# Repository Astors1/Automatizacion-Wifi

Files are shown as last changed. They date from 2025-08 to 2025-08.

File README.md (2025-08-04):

# Automatizacion wifi
Proyecto: Automatizaación WIFI Y infrarrojo. Alumnos: Alliana Facundo y Agustin Astorga ,con colaboracion de Alejo Guerra. Profesor: Martin Leguizamon. *Descripción del proyecto: Este dispositivo actúa como un control de tomacorrientes, donde se pueden agregar diferentes dispositivos, y permite apagarlos o prenderlos mediante una página web con interruptores. Además, cuenta con un sistema de control de seguridad (solo se puede activar manualmente)por infrarrojo, en caso de que no sea posible conectarse por WiFi. Objetivo: El objetivo principal es mejorar el control de dispositivos (luces, herramientas, etc.) de manera más práctica y permitir su manejo a distancia. En versiones anteriores, este dispositivo funcionaba mediante Bluetooth, lo que presentaba varias limitaciones: un alcance de solo 1 metro y la necesidad de instalar una aplicación en el teléfono móvil para su uso. En esta nueva versión, se mejorará la conexión a través de WiFi, lo que permitirá un mayor alcance y eliminará la necesidad de instalar aplicaciones adicionales, ya que funcionará mediante una dirección IP. Sin embargo, para situaciones en las que no se disponga de WiFi, el dispositivo contará con una opción de control por infrarrojos, que se podrá activar manualmente. Esta opción tendrá un alcance más limitado, pero ofrecerá una solución práctica y segura para su control. Listado de materiales/fuentes: • Microcontrolador ESP32/ (embebido reciclado) • Resistencias/optocopladores /transistores/pulsadores/rectificadores, etc (reciclados) • Relays x4 (reciclados) • Módulo infrarrojo (emisor/transmisor) ($8.000) • placa cobre doble faz (ya comprada) • Estaño, conectores, cables, etc ($10.000) Costo aproximado: $20.000.

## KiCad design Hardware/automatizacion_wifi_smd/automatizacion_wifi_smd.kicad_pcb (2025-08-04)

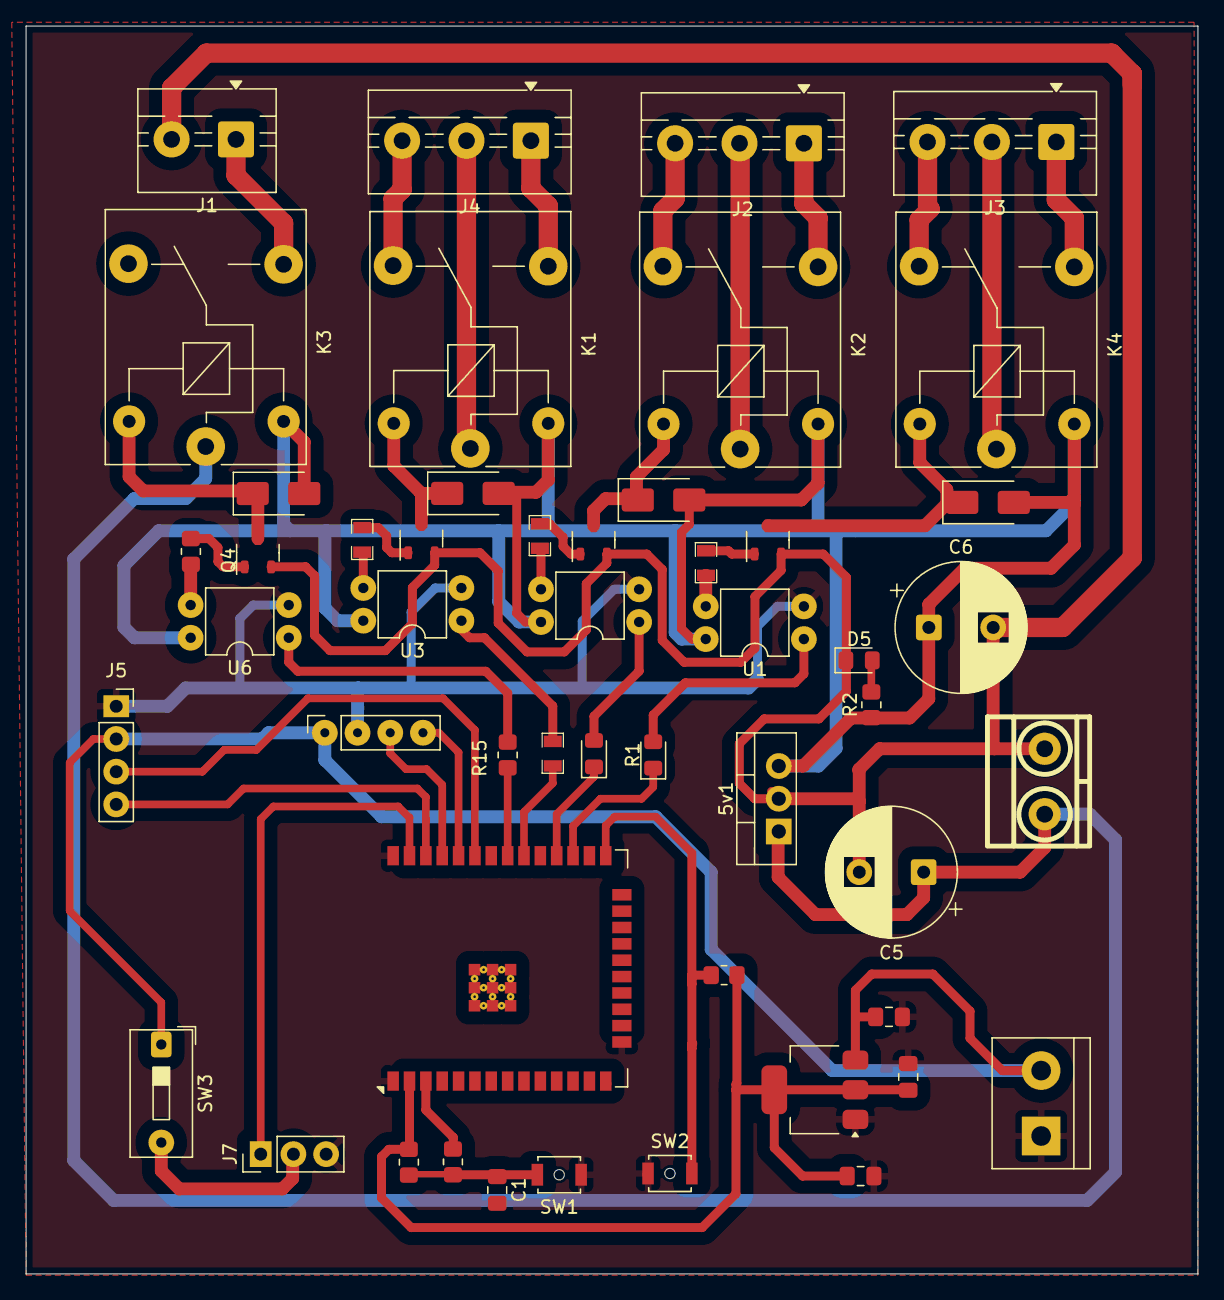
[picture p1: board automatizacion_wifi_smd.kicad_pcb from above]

Board: 2 copper layers, 91.0 x 96.9 mm, 50 parts (0 on the bottom side), 46 nets.

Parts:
5v1: LM7805_TO220; TO-220-3_Vertical
C1: 100nF; C_0805_2012Metric_Pad1.18x1.45mm_HandSolder
C2, C4: 10 uF; C_0805_2012Metric_Pad1.18x1.45mm_HandSolder
C3: 100 nF; C_0805_2012Metric_Pad1.18x1.45mm_HandSolder
C5, C6: 100uf; CP_Radial_D10.0mm_P5.00mm
D1, D2, D3, D4: DIODE; D_SMA
D5: LED; LED_0805_2012Metric_Pad1.15x1.40mm_HandSolder
J1: Screw_Terminal_01x02; TerminalBlock_MaiXu_MX126-5.0-02P_1x02_P5.00mm
J2, J3, J4: Screw_Terminal_01x03; TerminalBlock_MaiXu_MX126-5.0-03P_1x03_P5.00mm
J5, J6: Conn_01x04_Pin; PinSocket_1x04_P2.54mm_Vertical
J7: Conn_01x03_Pin; PinHeader_1x03_P2.54mm_Vertical
K1, K2, K3, K4: RELAY_C; Relay_SPDT_SANYOU_SRD_Series_Form_C
Q1, Q2, Q3, Q4: 2N3904; P200_SOT-23
R1, R4: R; LED_0805_2012Metric_Pad1.15x1.40mm_HandSolder
R2: 2.2k; R_0805_2012Metric_Pad1.20x1.40mm_HandSolder
R3, R6, R9: R; R_0805
R7: 1k; R_0805
R10, R11, R12: 10K; R_0805_2012Metric_Pad1.20x1.40mm_HandSolder
R15, R17: R; R_0805_2012Metric_Pad1.20x1.40mm_HandSolder
SW1, SW2: SW_Push; SW_SPST_B3U-1000P-B
SW3: SW_SPST; SW_DIP_SPSTx01_Slide_9.78x4.72mm_W7.62mm_P2.54mm
U1, U2, U3, U6: PC817; DIP-4_W7.62mm
U4: ESP32-WROOM-32E__4MB_; ESP32-WROOM-32E
U5: NCP1117-1.5_SOT223; SOT-223-3_TabPin2
bornera1: bornera; BORNERA2_AZUL
bornera2: bornera; TerminalBlock_bornier-2_P5.08mm

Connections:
/3.3V: C3.2, C4.1, R10.1, R11.1, U4.2 (3V3), U5.2 (VO)
/5V: 5v1.3 (VO), C6.1, D1.2 (K), D2.2 (K), D3.2 (K), D4.2 (K), K1.2, K2.2, K3.2, K4.2, R2.1, U1.4, U2.4, U3.4, U6.4
/5VES: C2.1, J5.2, J6.1, SW3.1 (A), U5.3 (VI), bornera2.2
/C1: J4.2, K1.1
/C2: J3.2, K4.1
/C3: J2.2, K2.1
/EN: R12.2, U4.3 (EN)
/FLASH: R11.2, SW2.2, U4.25 (IO0)
/GNDE: C1.2, C2.2, C3.1, C4.2, J5.1, J6.2, J7.3, SW1.1, SW2.1, U1.2, U2.2, U3.2, U4.1 (GND), U4.15 (GND), U4.38 (GND), U5.1 (GND), U6.2, bornera2.1
/NC1: J4.3, K1.4
/NC2: J3.3, K4.4
/NC3: J2.3, K2.4
/NO1: J4.1, K1.3
/NO2: J3.1, K4.3
/NO3: J2.1, K2.3
/NO4: J1.1, K3.3
/R1: R7.1, U4.30 (IO18)
/R2: R1.1, U4.27 (IO16)
/R3: R4.1, U4.28 (IO17)
/R4: R15.1, U4.31 (IO19)
/RX: J6.4, U4.34 (RXD0)
/S: J7.1, U4.37 (IO23)
/SCL: J5.4, U4.36 (IO22)
/SDA: J5.3, U4.33 (IO21)
/SWITCH: C1.1, R10.2, R12.1, SW1.2
/TX: J6.3, U4.35 (TXD0)
/VIN: C5.1, K3.1, bornera1.1
GND: 5v1.2 (GND), C5.2, C6.2, D5.1 (K), J1.2, Q1.2 (E), Q2.2 (E), Q3.2 (E), Q4.2 (E), bornera1.2
unnamed: D1.1 (A), K4.5, Q3.3 (C)
unnamed: D2.1 (A), K2.5, Q2.3 (C)
unnamed: D3.1 (A), K1.5, Q1.3 (C)
unnamed: D4.1 (A), K3.5, Q4.3 (C)
unnamed: D5.2 (A), R2.2
unnamed: J7.2, SW3.2 (B)
unnamed: Q1.1 (B), R9.2
unnamed: Q2.1 (B), R6.2
unnamed: Q3.1 (B), R3.2
unnamed: Q4.1 (B), R17.2
unnamed: R1.2, U1.1
unnamed: R3.1, U1.3
unnamed: R4.2, U2.1
unnamed: R6.1, U2.3
unnamed: R7.2, U3.1
unnamed: R9.1, U3.3
unnamed: R15.2, U6.1
unnamed: R17.1, U6.3

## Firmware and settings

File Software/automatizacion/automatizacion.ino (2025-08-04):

#include <WiFi.h>

const char* ssid = "ZTE";
const char* password = "mesi1234";

WiFiServer server(80);
String header;

// Estados de los pines
String output16State = "off";
String output17State = "off";
String output18State = "off";
String output19State = "off";

// Pines utilizados
const int output16 = 16;
const int output17 = 17;
const int output18 = 18;
const int output19 = 19;

unsigned long currentTime = millis();
unsigned long previousTime = 0; 
const long timeoutTime = 2000;

void setup() {
  Serial.begin(115200);
  pinMode(output16, OUTPUT);
  pinMode(output17, OUTPUT);
  pinMode(output18, OUTPUT);
  pinMode(output19, OUTPUT);

  digitalWrite(output16, LOW);
  digitalWrite(output17, LOW);
  digitalWrite(output18, LOW);
  digitalWrite(output19, LOW);

  Serial.print("Connecting to ");
  Serial.println(ssid);
  WiFi.begin(ssid, password);
  while (WiFi.status() != WL_CONNECTED) {
    delay(500);
    Serial.print(".");
  }
  Serial.println("");
  Serial.println("WiFi connected.");
  Serial.println("IP address: ");
  Serial.println(WiFi.localIP());
  server.begin();
}

void loop() {
  WiFiClient client = server.available();

  if (client) {
    currentTime = millis();
    previousTime = currentTime;
    Serial.println("New Client.");
    String currentLine = "";

    while (client.connected() && currentTime - previousTime <= timeoutTime) {
      currentTime = millis();
      if (client.available()) {
        char c = client.read();
        Serial.write(c);
        header += c;
        if (c == '\n') {
          if (currentLine.length() == 0) {
            client.println("HTTP/1.1 200 OK");
            client.println("Content-type:text/html");
            client.println("Connection: close");
            client.println();

            // Control de pines
            if (header.indexOf("GET /16/on") >= 0) {
              Serial.println("GPIO 16 on");
              output16State = "on";
              digitalWrite(output16, HIGH);
            } else if (header.indexOf("GET /16/off") >= 0) {
              Serial.println("GPIO 16 off");
              output16State = "off";
              digitalWrite(output16, LOW);
            } else if (header.indexOf("GET /17/on") >= 0) {
              Serial.println("GPIO 17 on");
              output17State = "on";
              digitalWrite(output17, HIGH);
            } else if (header.indexOf("GET /17/off") >= 0) {
              Serial.println("GPIO 17 off");
              output17State = "off";
              digitalWrite(output17, LOW);
            } else if (header.indexOf("GET /18/on") >= 0) {
              Serial.println("GPIO 18 on");
              output18State = "on";
              digitalWrite(output18, HIGH);
            } else if (header.indexOf("GET /18/off") >= 0) {
              Serial.println("GPIO 18 off");
              output18State = "off";
              digitalWrite(output18, LOW);
            } else if (header.indexOf("GET /19/on") >= 0) {
              Serial.println("GPIO 19 on");
              output19State = "on";
              digitalWrite(output19, HIGH);
            } else if (header.indexOf("GET /19/off") >= 0) {
              Serial.println("GPIO 19 off");
              output19State = "off";
              digitalWrite(output19, LOW);
            }

            // Página web
            client.println("<!DOCTYPE html><html>");
            client.println("<head><meta name=\"viewport\" content=\"width=device-width, initial-scale=1\">");
            client.println("<link rel=\"icon\" href=\"data:,\">");
            client.println("<style>html { font-family: Helvetica; display: inline-block; margin: 0px auto; text-align: center;}");
            client.println(".button { background-color: #4CAF50; border: none; color: white; padding: 16px 40px;");
            client.println("text-decoration: none; font-size: 30px; margin: 2px; cursor: pointer;}");
            client.println(".button2 {background-color: #555555;}</style></head>");

            client.println("<body><h1>ESP32 Web Server</h1>");

            client.println("<p>GPIO 16 - State " + output16State + "</p>");
            if (output16State == "off") {
              client.println("<p><a href=\"/16/on\"><button class=\"button\">ON</button></a></p>");
            } else {
              client.println("<p><a href=\"/16/off\"><button class=\"button button2\">OFF</button></a></p>");
            }

            client.println("<p>GPIO 17 - State " + output17State + "</p>");
            if (output17State == "off") {
              client.println("<p><a href=\"/17/on\"><button class=\"button\">ON</button></a></p>");
            } else {
              client.println("<p><a href=\"/17/off\"><button class=\"button button2\">OFF</button></a></p>");
            }

            client.println("<p>GPIO 18 - State " + output18State + "</p>");
            if (output18State == "off") {
              client.println("<p><a href=\"/18/on\"><button class=\"button\">ON</button></a></p>");
            } else {
              client.println("<p><a href=\"/18/off\"><button class=\"button button2\">OFF</button></a></p>");
            }

            client.println("<p>GPIO 19 - State " + output19State + "</p>");
            if (output19State == "off") {
              client.println("<p><a href=\"/19/on\"><button class=\"button\">ON</button></a></p>");
            } else {
              client.println("<p><a href=\"/19/off\"><button class=\"button button2\">OFF</button></a></p>");
            }

            client.println("</body></html>");
            client.println();
            break;
          } else {
            currentLine = "";
          }
        } else if (c != '\r') {
          currentLine += c;
        }
      }
    }
    header = "";
    client.stop();
    Serial.println("Client disconnected.");
    Serial.println("");
  }
}

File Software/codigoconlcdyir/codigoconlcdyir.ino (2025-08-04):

#include <WiFi.h>
#include <Wire.h>
#include <LiquidCrystal_I2C.h>
#include <IRremote.h>

// LCD I2C (dirección 0x27)
LiquidCrystal_I2C lcd(0x27, 16, 2);

// Credenciales Wi-Fi
const char* ssid = "ZTE";
const char* password = "mesi1234";

// Servidor web en el puerto 80
WiFiServer server(80);

// Estados de pines
String output16State = "off";
String output17State = "off";
String output18State = "off";
String output19State = "off";

// Pines asignados a relés
const int output16 = 16;
const int output17 = 17;
const int output18 = 18;
const int output19 = 19;

// Pin del sensor IR
#define IR_RECEIVE_PIN 23

void setup() {
  Serial.begin(115200);

  // Inicializar LCD
  Wire.begin(21, 22); // SDA, SCL
  lcd.init();
  lcd.backlight();
  lcd.setCursor(0, 0);
  lcd.print("Conectando WiFi");

  // Inicializar pines de salida
  pinMode(output16, OUTPUT);
  pinMode(output17, OUTPUT);
  pinMode(output18, OUTPUT);
  pinMode(output19, OUTPUT);
  digitalWrite(output16, LOW);
  digitalWrite(output17, LOW);
  digitalWrite(output18, LOW);
  digitalWrite(output19, LOW);

  // Conectar a Wi-Fi
  WiFi.begin(ssid, password);
  while (WiFi.status() != WL_CONNECTED) {
    delay(500);
    Serial.print(".");
  }

  // Mostrar IP en LCD y consola
  lcd.clear();
  lcd.setCursor(0, 0);
  lcd.print("WiFi conectado!");
  lcd.setCursor(0, 1);
  lcd.print(WiFi.localIP());

  Serial.println();
  Serial.println("WiFi conectado.");
  Serial.print("IP: ");
  Serial.println(WiFi.localIP());

  server.begin();

  // Iniciar receptor IR
  IrReceiver.begin(IR_RECEIVE_PIN, ENABLE_LED_FEEDBACK);
  Serial.println("IR listo.");
}

void loop() {
  // Escuchar comandos IR
  if (IrReceiver.decode()) {
    uint8_t cmd = IrReceiver.decodedIRData.command;
    Serial.print("Comando IR: 0x");
    Serial.println(cmd, HEX);

    // Mapeo de botones IR a relés
    switch (cmd) {
      case 0x10:  // Botón 1
        digitalWrite(output16, !digitalRead(output16));
        output16State = digitalRead(output16) ? "on" : "off";
        break;
      case 0x30:  // Botón 2
        digitalWrite(output17, !digitalRead(output17));
        output17State = digitalRead(output17) ? "on" : "off";
        break;
      case 0x40:  // Botón 3
        digitalWrite(output18, !digitalRead(output18));
        output18State = digitalRead(output18) ? "on" : "off";
        break;
      case 0x50:  // Botón 4
        digitalWrite(output19, !digitalRead(output19));
        output19State = digitalRead(output19) ? "on" : "off";
        break;
    }
    IrReceiver.resume();
  }

  // Atender cliente web
  WiFiClient client = server.available();
  if (client) {
    Serial.println("Nuevo cliente.");
    String request = "";
    int newlines = 0;
    unsigned long timeout = millis() + 3000;

    while (client.connected() && millis() < timeout) {
      if (client.available()) {
        char c = client.read();
        request += c;
        if (c == '\n') {
          newlines++;
          if (newlines == 2) break;
        } else if (c != '\r') {
          newlines = 0;
        }
      }
    }

    if (request.indexOf("GET /16/on") >= 0) {
      digitalWrite(output16, HIGH); output16State = "on";
    } else if (request.indexOf("GET /16/off") >= 0) {
      digitalWrite(output16, LOW); output16State = "off";
    }
    if (request.indexOf("GET /17/on") >= 0) {
      digitalWrite(output17, HIGH); output17State = "on";
    } else if (request.indexOf("GET /17/off") >= 0) {
      digitalWrite(output17, LOW); output17State = "off";
    }
    if (request.indexOf("GET /18/on") >= 0) {
      digitalWrite(output18, HIGH); output18State = "on";
    } else if (request.indexOf("GET /18/off") >= 0) {
      digitalWrite(output18, LOW); output18State = "off";
    }
    if (request.indexOf("GET /19/on") >= 0) {
      digitalWrite(output19, HIGH); output19State = "on";
    } else if (request.indexOf("GET /19/off") >= 0) {
      digitalWrite(output19, LOW); output19State = "off";
    }

    // Respuesta web
    client.println("HTTP/1.1 200 OK");
    client.println("Content-type:text/html");
    client.println("Connection: close");
    client.println();

    client.println("<!DOCTYPE html><html><head><meta name='viewport' content='width=device-width, initial-scale=1'>");
    client.println("<style>html { font-family: Helvetica; text-align: center;} .button { background-color: #4CAF50; border: none; color: white; padding: 16px 40px; font-size: 30px; margin: 2px; cursor: pointer;} .button2 {background-color: #555555;}</style>");
    client.println("</head><body><h1>ESP32 Web Server</h1>");

    client.println("<p>GPIO 16 - Estado: " + output16State + "</p>");
    client.println("<p><a href=\"/16/" + String(output16State == "off" ? "on" : "off") + "\"><button class=\"button" + String(output16State == "on" ? " button2" : "") + "\">" + String(output16State == "off" ? "ON" : "OFF") + "</button></a></p>");

    client.println("<p>GPIO 17 - Estado: " + output17State + "</p>");
    client.println("<p><a href=\"/17/" + String(output17State == "off" ? "on" : "off") + "\"><button class=\"button" + String(output17State == "on" ? " button2" : "") + "\">" + String(output17State == "off" ? "ON" : "OFF") + "</button></a></p>");

    client.println("<p>GPIO 18 - Estado: " + output18State + "</p>");
    client.println("<p><a href=\"/18/" + String(output18State == "off" ? "on" : "off") + "\"><button class=\"button" + String(output18State == "on" ? " button2" : "") + "\">" + String(output18State == "off" ? "ON" : "OFF") + "</button></a></p>");

    client.println("<p>GPIO 19 - Estado: " + output19State + "</p>");
    client.println("<p><a href=\"/19/" + String(output19State == "off" ? "on" : "off") + "\"><button class=\"button" + String(output19State == "on" ? " button2" : "") + "\">" + String(output19State == "off" ? "ON" : "OFF") + "</button></a></p>");

    client.println("</body></html>");
    client.println();
    client.stop();
    Serial.println("Cliente desconectado.");
  }
}
